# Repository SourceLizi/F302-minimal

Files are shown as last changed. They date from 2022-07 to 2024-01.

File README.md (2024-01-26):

# STM32F302C8T6最小系统

这个硬件项目是用于取代原先F103C8T6开发板而制作的，也为其他硬件项目提供参考。相比于同等密度的F103，STM32F302拥有一个高速（5MSPS）ADC，并且额外增加了一个运放和三个比较器，适合模数混合的应用。另外由于其定时器带有输入时钟倍频的功能，其输出分辨率比F103更高。

板载功能除了必须的调试口，复位电路以及晶振电路之外，还引出了USB接口与两枚测试用的LED，另外还增加了一颗IMU（QMI8658C）的位置，用于实践测试IMU解算算法以及评估IMU性能。

最小系统板还配备了一块带有三个半桥驱动的底板（原来的目的是用于驱动电机，后面发现不符合要求），适合用于作为功率级使用。三个半桥均带有电流检测的功能。由核心板的5V经过升压达到11V输入驱动IC，而电流检测放大器的供电则由5V经线性稳压供电。
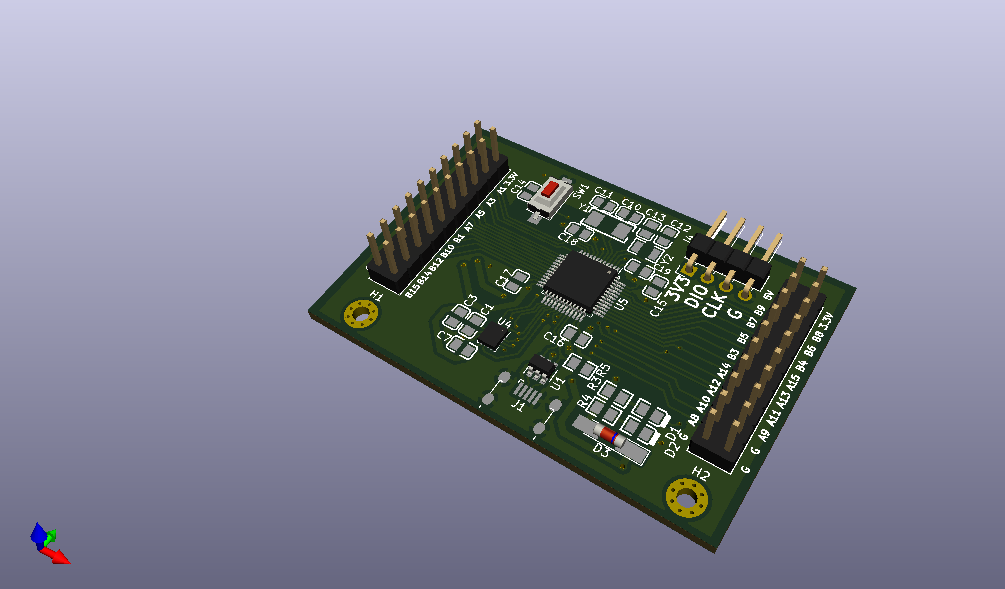
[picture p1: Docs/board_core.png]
board_core


## 硬件说明

1. 最小系统板内主控的模拟电源与数字电源可分开供电，可以选择使用额外的LDO LP5907为模拟电源供电，或者拖锡连接JP1直接连接模数电源

2. AMS1117输入输出的二极管D3必须焊接，否则会出现在调试时只接入3.3V而1117发热严重的情况

3. IMU的中断管脚INT1与栅极驱动底板的驱动输入引脚有冲突，按照目前的设计二选其一使用

## 软件说明

`f302_minimal_test` 内为早期测试核心板的代码，基本没有实际用途

`imu_f302` 内为IMU测试解算代码，读取QMI8658C解算角度，并将其通过USB虚拟串口发送至匿名地面站上位机。EKF解算算法详见[这篇博客](https://sourcelizi.github.io/202304/imu-practice/)，新增加的ESKF解算算法见[这篇博客](https://sourcelizi.github.io/202311/imu-practice3/)

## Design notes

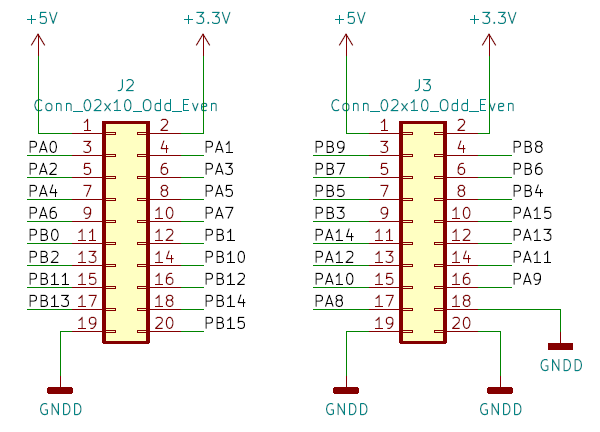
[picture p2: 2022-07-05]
Hardware/Core/pinout.png

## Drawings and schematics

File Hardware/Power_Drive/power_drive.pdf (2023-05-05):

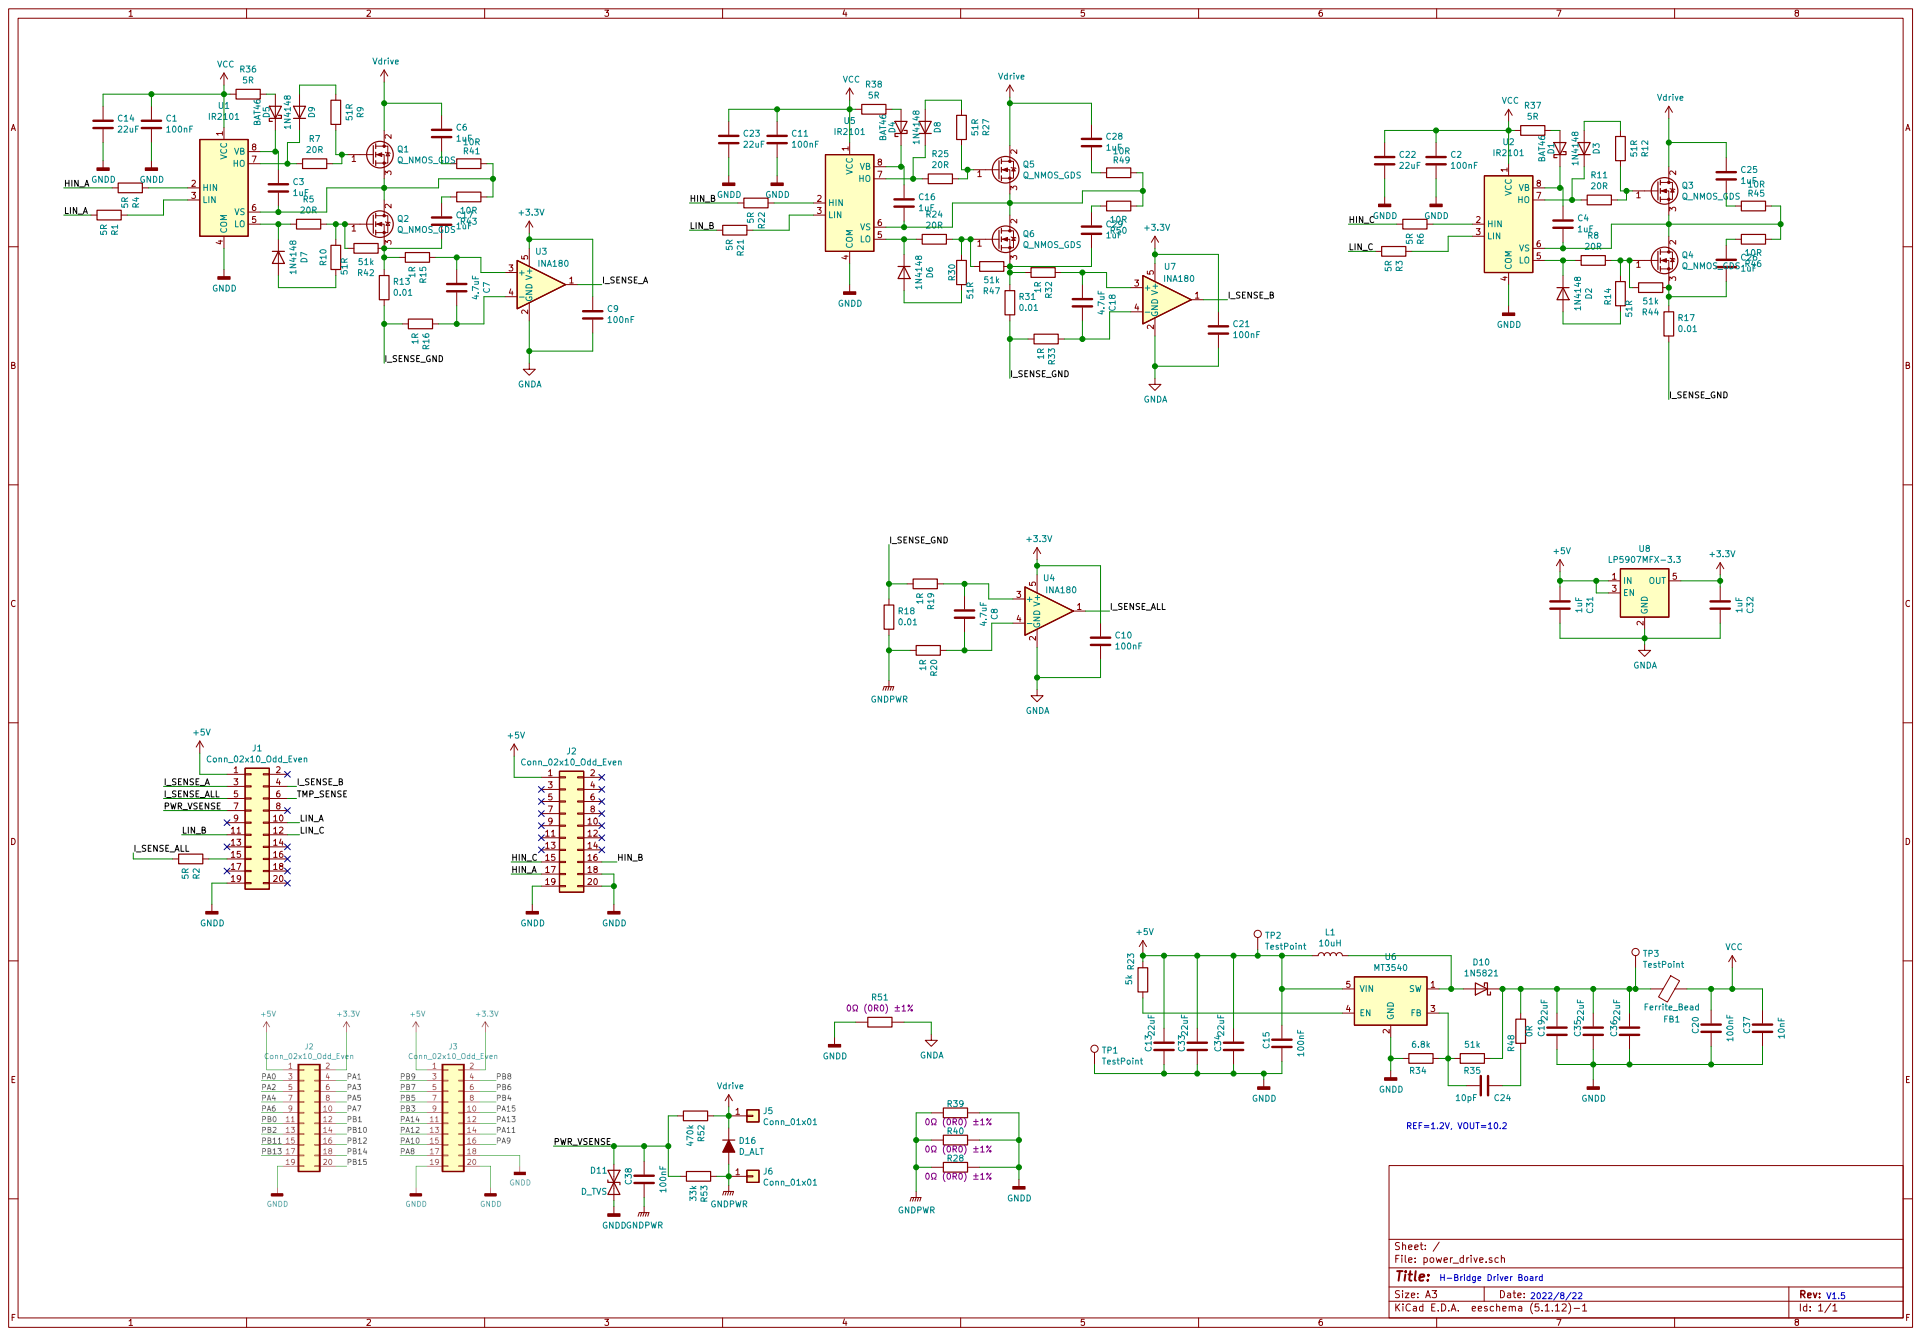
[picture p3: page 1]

H-Bridge Driver Board REF=1.2V, VOUT=10.2

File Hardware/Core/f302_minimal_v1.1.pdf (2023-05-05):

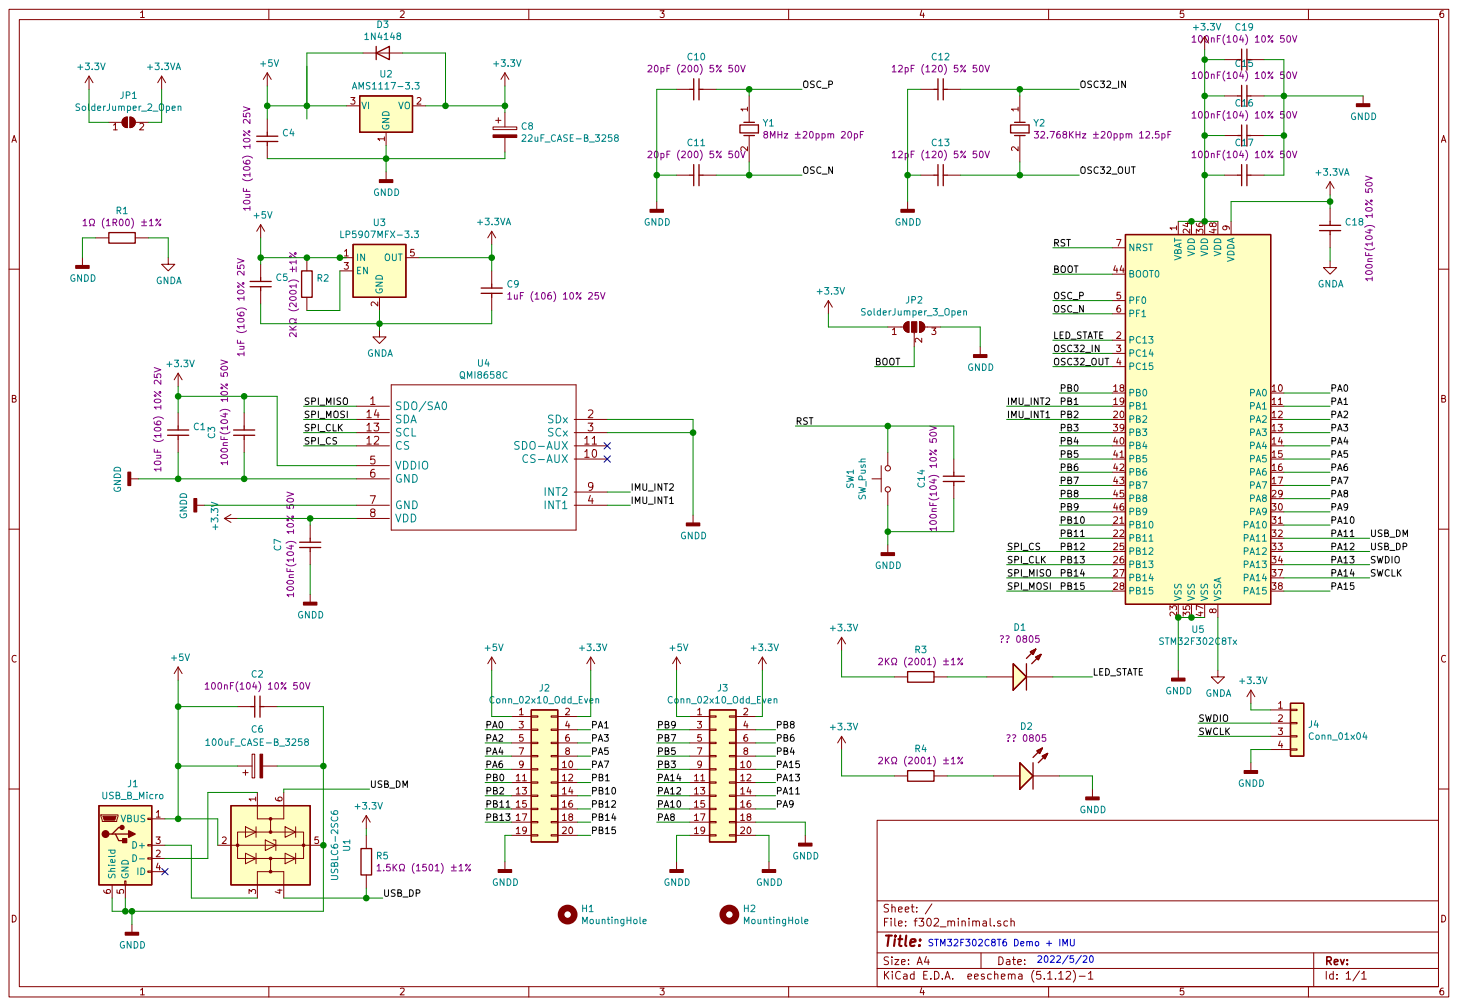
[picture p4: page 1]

1 VDD 24 VDD 36 VDD 48 VDDA

9 VSS 23 VSS 35 VSS 47 VSSA

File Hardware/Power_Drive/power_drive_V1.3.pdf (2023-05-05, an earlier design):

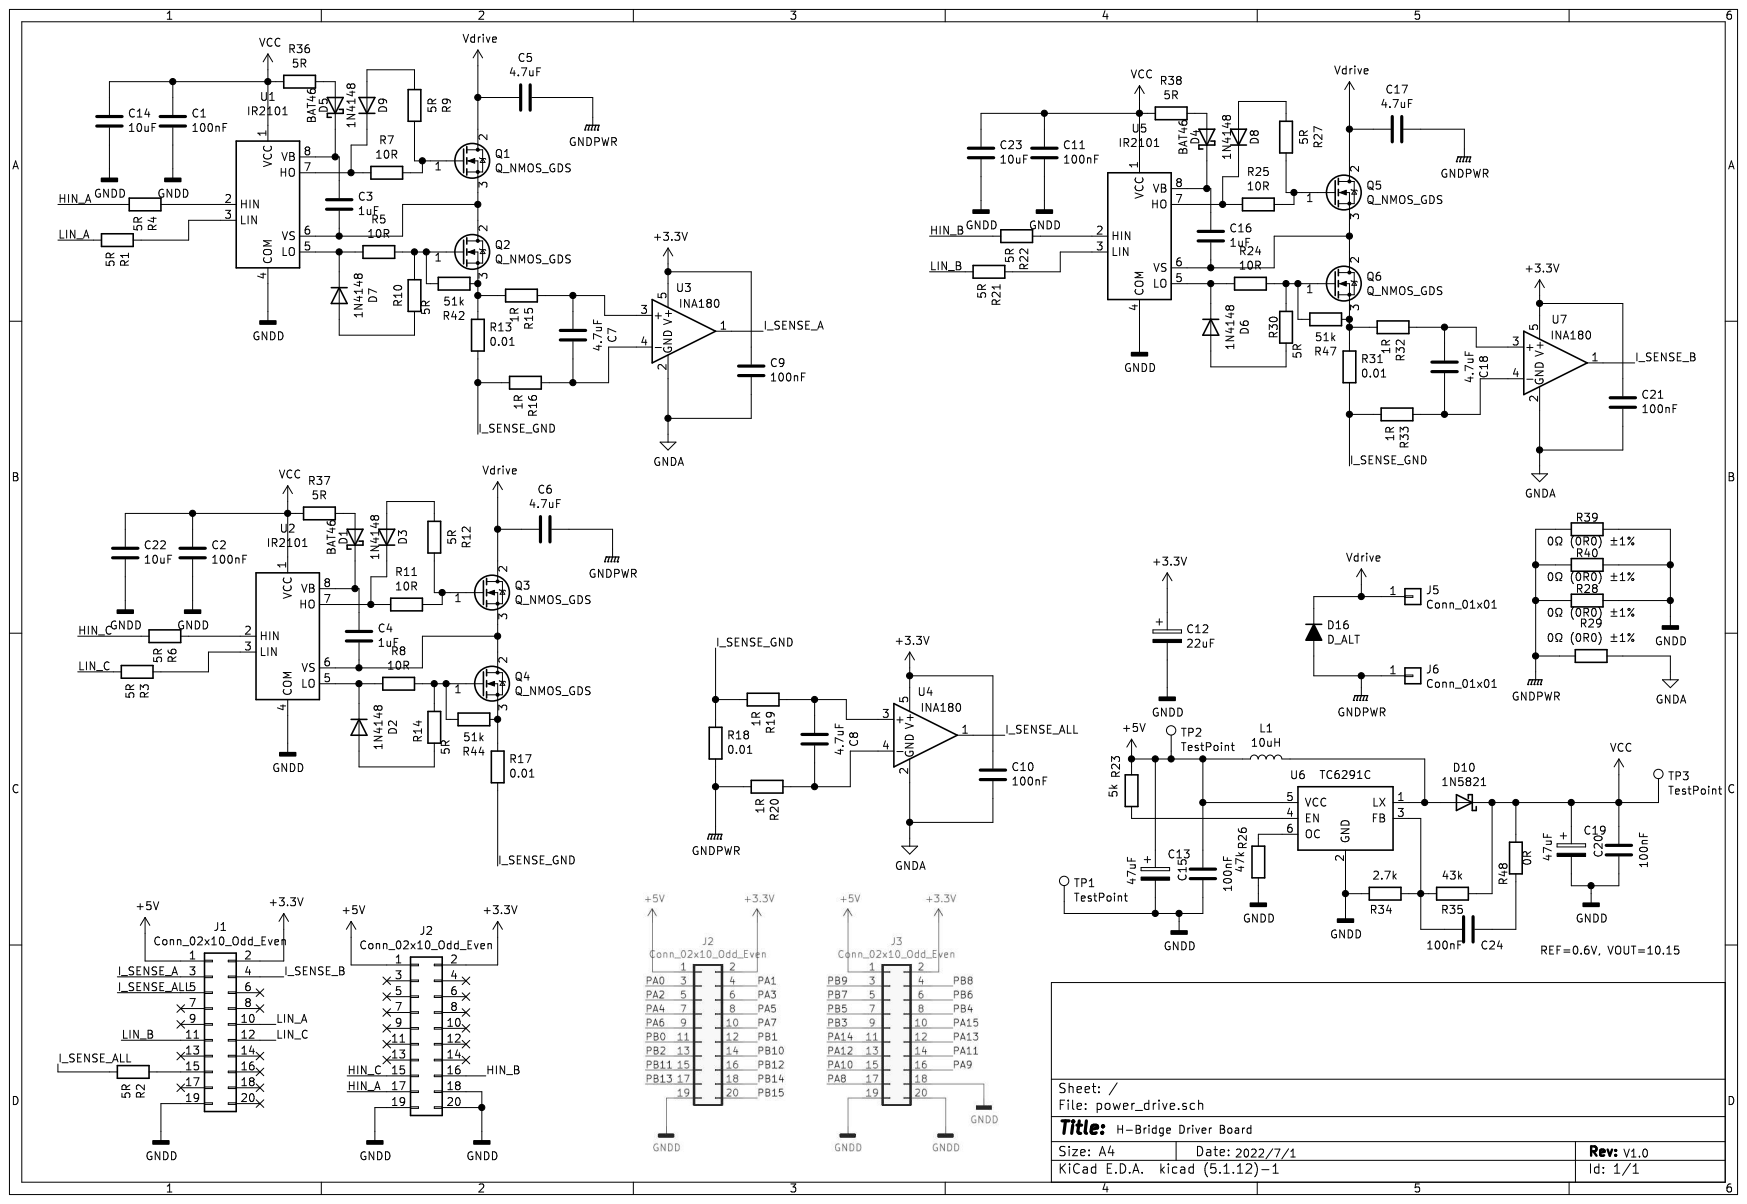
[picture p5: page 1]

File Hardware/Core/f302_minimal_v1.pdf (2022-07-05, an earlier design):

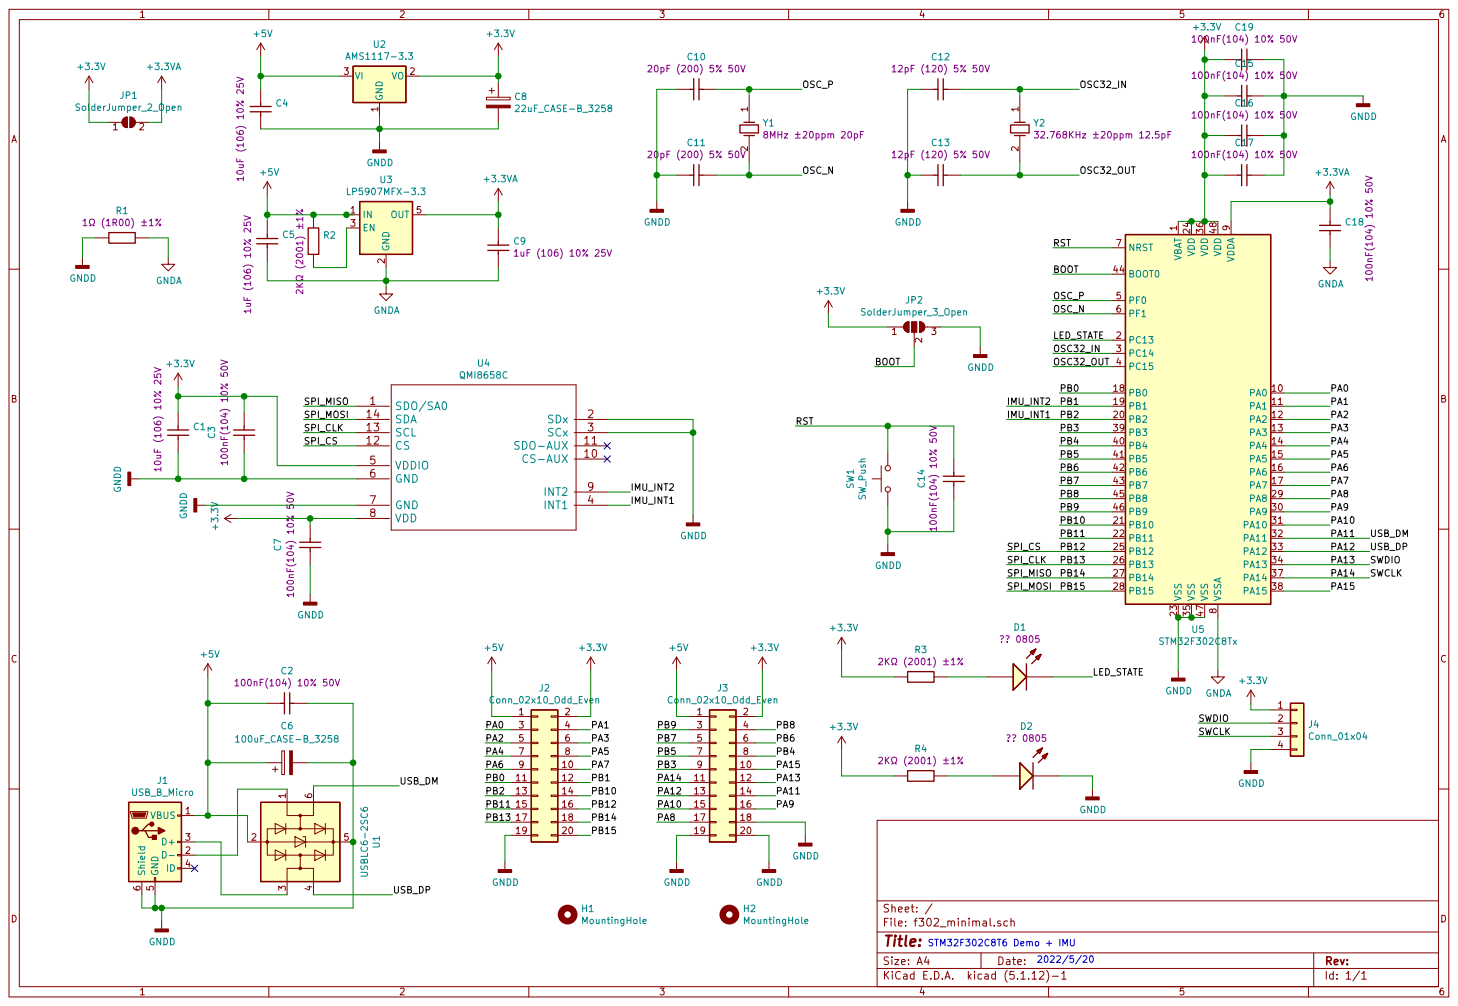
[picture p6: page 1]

1 VO 2 VI 3 U2 AMS1117-3.3 BOOT0 44 NRST 7 PA0 10 PA1 11 PA10 31 PA11 32 PA12 33 PA13 34 PA14 37 PA15 38 PA2 12 PA3 13 PA4 14 PA5 15 PA6 16 PA7 17 PA8 29 PA9 30 PB0 18 PB1 19 PB10 21 PB11 22 PB12 25 PB13 26 PB14 27 PB15 28 PB2 20 PB3 39 PB4 40 PB5 41 PB6 42 PB7 43 PB8 45 PB9 46 PC13 2 PC14 3 PC15 4 PF0 5 PF1 6 VBAT

1 VDD 24 VDD 36 VDD 48 VDDA

9 VSS 23 VSS 35 VSS 47 VSSA

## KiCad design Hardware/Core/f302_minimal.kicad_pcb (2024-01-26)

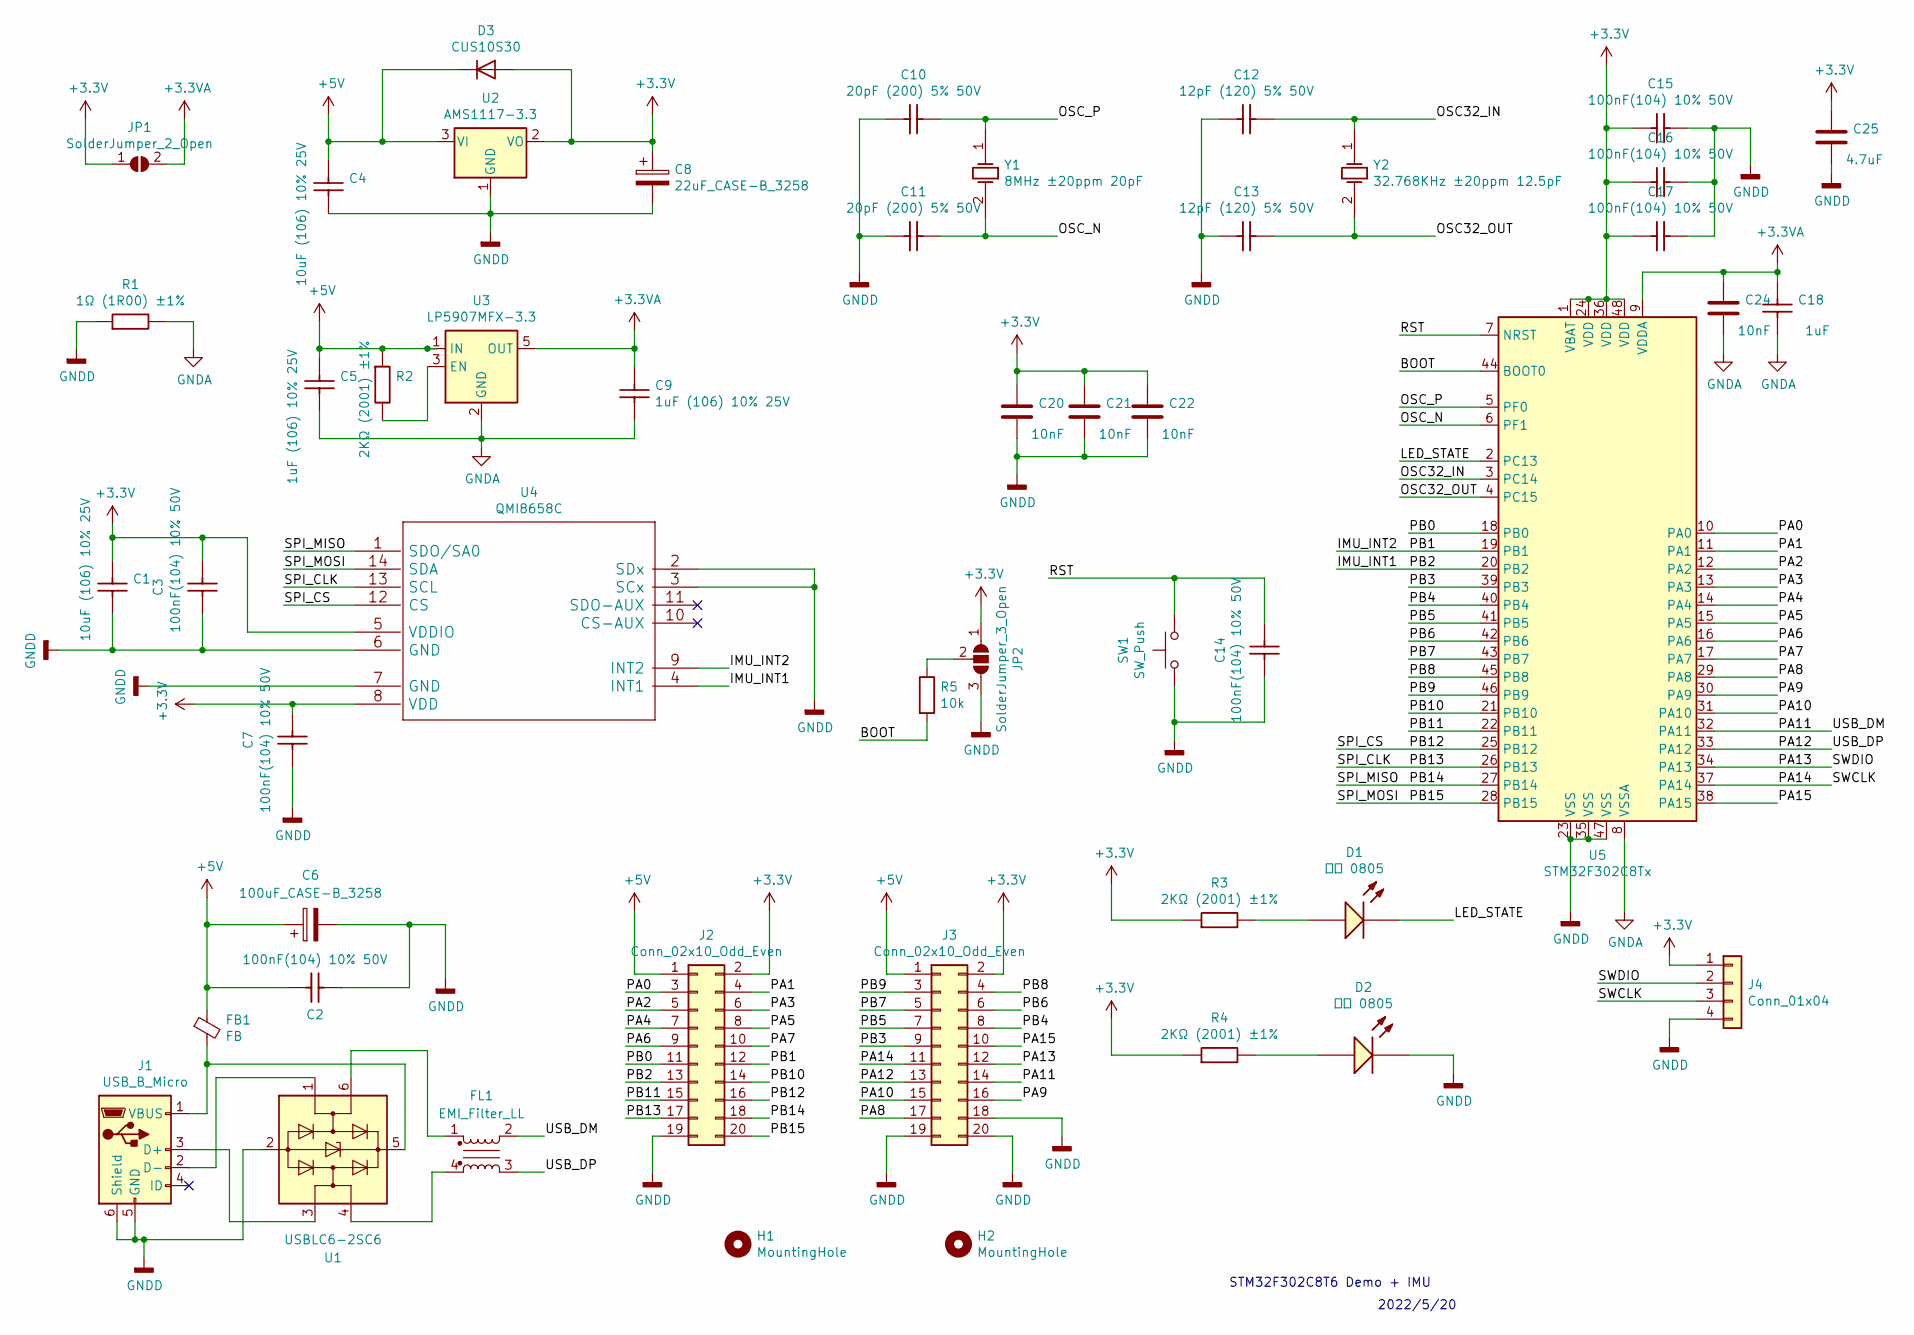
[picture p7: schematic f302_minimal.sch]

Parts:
C1, C4, C5, C9: 0805_10uF__106_10%_25V; 0805_C
C2, C3, C7, C14, C15, C16, C17: 0805_100nF_104_10%_50V; 0805_C
C6: 100uF_CASE-B_3258; CP_EIA-3528-21_Kemet-B_Pad1.50x2.35mm_HandSolder
C8: 22uF_CASE-B_3258; CP_EIA-3528-21_Kemet-B_Pad1.50x2.35mm_HandSolder
C10, C11: 0805_20pF__200_5%_50V; 0805_C
C12, C13: 0805_12pF__120_5%_50V; 0603_C
C18: 1uF; 0805_C
C20, C21, C22, C24: 10nF; C_0603_1608Metric_Pad1.08x0.95mm_HandSolder
C25: 4.7uF; C_0805_2012Metric_Pad1.18x1.45mm_HandSolder
D1: 0805_翠绿; 0805_LED_S1
D2: 0805_红灯; 0805_LED_S1
D3: CUS10S30; D_SOD-323_HandSoldering
FB1: FB; R_0805_2012Metric_Pad1.20x1.40mm_HandSolder
FL1: EMI_Filter_LL; DLW21SN900SQ2L
H1, H2: MountingHole; MountingHole_2.2mm_M2_Pad_Via
J1: USB_B_Micro; USB_MicroB
J2, J3: Conn_02x10_Odd_Even; PinHeader_2x10_P2.54mm_Vertical
J4: Conn_01x04; PinHeader_1x04_P2.54mm_Horizontal
JP1: SolderJumper_2_Open; SolderJumper-2_P1.3mm_Open_RoundedPad1.0x1.5mm
JP2: SolderJumper_3_Open; SolderJumper-3_P1.3mm_Open_RoundedPad1.0x1.5mm_NumberLabels
R1: 0603_1Ω__1R00_1%; 0603_R
R2, R3, R4: 0805_2KΩ__2001_1%; 0805_R
R5: 10k; R_0603_1608Metric_Pad0.98x0.95mm_HandSolder
SW1: SW_Push; SW_SPST_CK_RS282G05A3
U1: USBLC6-2SC6; SOT-23-6_Handsoldering
U2: AMS1117-3.3; SOT-223-3_TabPin2
U3: LP5907MFX-3.3; SOT-23-5
U4: QMI8658C; Bosch_LGA-14_3x2.5mm_P0.5mm
U5: STM32F302C8Tx; LQFP-48_7x7mm_P0.5mm
Y1: SMD-5032_2P_8MHz_20ppm_20pF; SMD-5032_2P
Y2: SMD-3215_2P_32.768KHz_20ppm_12.5pF; SMD-3215_2P_FC_-_135

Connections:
+3.3VA: C9.2, C18.1, C24.1, JP1.2 (B), U3.5 (OUT), U5.9 (VDDA)
+3V3: C1.1, C3.2, C7.2, C8.1, C15.1, C16.1, C17.1, C20.1, C21.1, C22.1, C25.1, D3.2 (A), J2.2, J3.2, J4.1, JP1.1 (A), JP2.1 (A), R3.1, R4.1, U2.2 (VO), U4.5 (VDDIO), U4.8 (VDD), U5.1 (VBAT), U5.24 (VDD), U5.36 (VDD), U5.48 (VDD)
+5V: C2.1, C4.1, C5.2, C6.1, D3.1 (K), FB1.1, J2.1, J3.1, R2.1, U2.3 (VI), U3.1 (IN)
/BOOT: R5.2, U5.44 (BOOT0)
/IMU_INT1: J2.13, U4.4 (INT1), U5.20 (PB2)
/IMU_INT2: J2.12, U4.9 (INT2), U5.19 (PB1)
/LED_STATE: D1.K, U5.2 (PC13)
/OSC32_IN: C12.2, U5.3 (PC14), Y2.1 (OSC1)
/OSC32_OUT: C13.2, U5.4 (PC15), Y2.2 (OSC2)
/OSC_N: C11.2, U5.6 (PF1), Y1.2 (OSC2)
/OSC_P: C10.2, U5.5 (PF0), Y1.1 (OSC1)
/PA0: J2.3, U5.10 (PA0)
/PA1: J2.4, U5.11 (PA1)
/PA2: J2.5, U5.12 (PA2)
/PA3: J2.6, U5.13 (PA3)
/PA4: J2.7, U5.14 (PA4)
/PA5: J2.8, U5.15 (PA5)
/PA6: J2.9, U5.16 (PA6)
/PA7: J2.10, U5.17 (PA7)
/PA8: J3.17, U5.29 (PA8)
/PA9: J3.16, U5.30 (PA9)
/PA10: J3.15, U5.31 (PA10)
/PA11: FL1.2, J3.14, U5.32 (PA11)
/PA12: FL1.3, J3.13, U5.33 (PA12)
/PA13: J3.12, J4.2, U5.34 (PA13)
/PA14: J3.11, J4.3, U5.37 (PA14)
/PA15: J3.10, U5.38 (PA15)
/PB0: J2.11, U5.18 (PB0)
/PB3: J3.9, U5.39 (PB3)
/PB4: J3.8, U5.40 (PB4)
/PB5: J3.7, U5.41 (PB5)
/PB6: J3.6, U5.42 (PB6)
/PB7: J3.5, U5.43 (PB7)
/PB8: J3.4, U5.45 (PB8)
/PB9: J3.3, U5.46 (PB9)
/PB10: J2.14, U5.21 (PB10)
/PB11: J2.15, U5.22 (PB11)
/PB12: J2.16, U4.12 (CS), U5.25 (PB12)
/PB13: J2.17, U4.13 (SCL), U5.26 (PB13)
/PB14: J2.18, U4.1 (SDO/SA0), U5.27 (PB14)
/PB15: J2.20, U4.14 (SDA), U5.28 (PB15)
/RST: C14.2, SW1.2, U5.7 (NRST)
GNDA: C5.1, C9.1, C18.2, C24.2, R1.2, U3.2 (GND), U5.8 (VSSA)
GNDD: C1.2, C2.2, C3.1, C4.2, C6.2, C7.1, C8.2, C10.1, C11.1, C12.1, C13.1, C14.1, C15.2, C16.2, C17.2, C20.2, C21.2, C22.2, C25.2, D2.K, J1.5 (GND), J1.6 (Shield), J2.19, J3.18, J3.19, J3.20, J4.4, JP2.3 (B), R1.1, SW1.1, U1.2 (GND), U2.1 (GND), U4.2 (SDx), U4.3 (SCx), U4.6 (GND), U4.7 (GND), U5.23 (VSS), U5.35 (VSS), U5.47 (VSS); also elsewhere on the board
unnamed: D1.A, R3.2
unnamed: D2.A, R4.2
unnamed 46: FB1.2, J1.1 (VBUS), U1.5 (VBUS); also elsewhere on the board
unnamed: FL1.1, U1.6 (I/O1)
unnamed: FL1.4, U1.4 (I/O2)
unnamed 49: J1.2 (D-), U1.1 (I/O1); also elsewhere on the board
unnamed 50: J1.3 (D+), U1.3 (I/O2); also elsewhere on the board
unnamed 51: J1.4 (ID); also elsewhere on the board
unnamed: JP2.2 (C), R5.1
unnamed: R2.2, U3.3 (EN)

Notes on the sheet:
STM32F302C8T6 Demo + IMU
2022/5/20

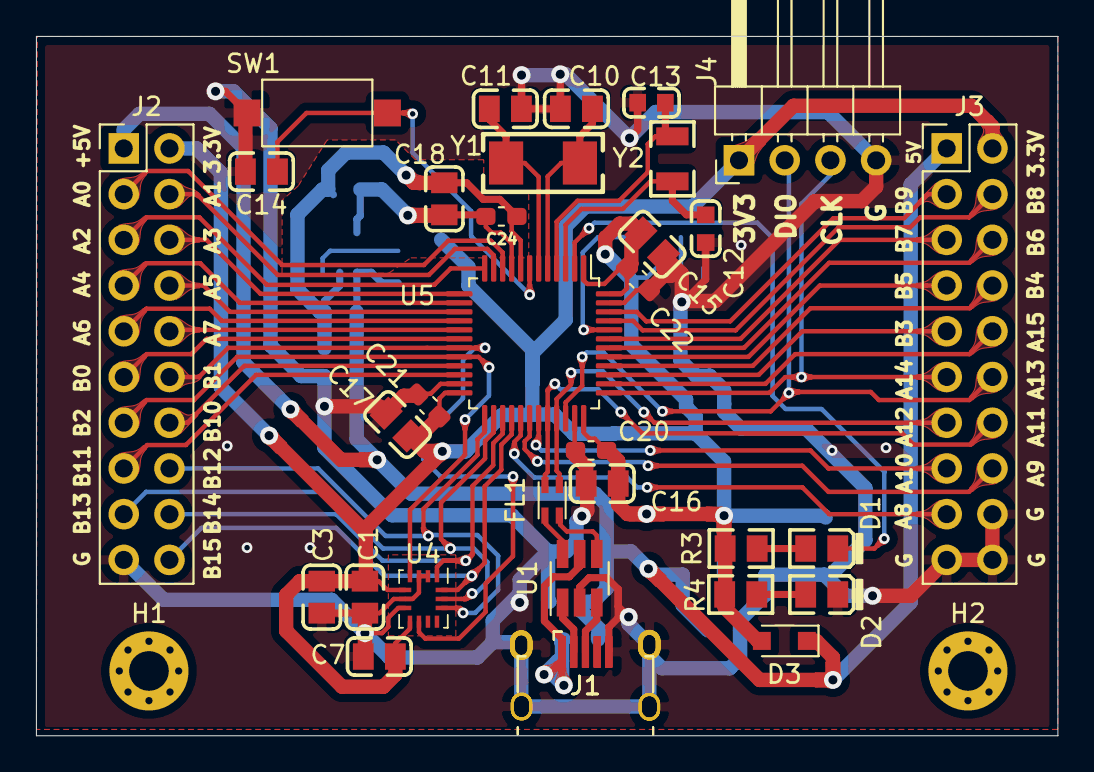
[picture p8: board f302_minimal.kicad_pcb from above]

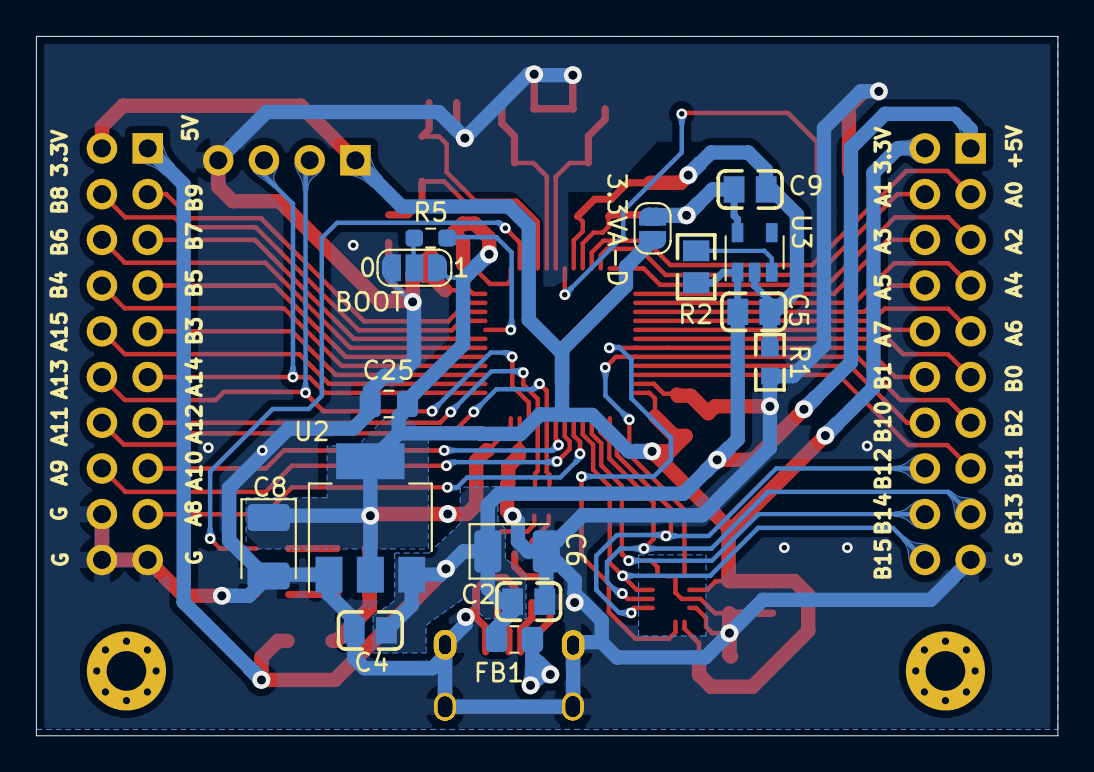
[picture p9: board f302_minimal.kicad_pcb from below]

Board: 2 copper layers, 56.8 x 38.8 mm, 50 parts (15 on the bottom side), 54 nets.

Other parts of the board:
J1#2: USB_B_Micro; USB_MicroB

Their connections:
GNDD: J1#2.5, J1#2.6; also elsewhere on the board
unnamed 46: J1#2.1; also elsewhere on the board
unnamed 49: J1#2.2; also elsewhere on the board
unnamed 50: J1#2.3; also elsewhere on the board
unnamed 51: J1#2.4; also elsewhere on the board

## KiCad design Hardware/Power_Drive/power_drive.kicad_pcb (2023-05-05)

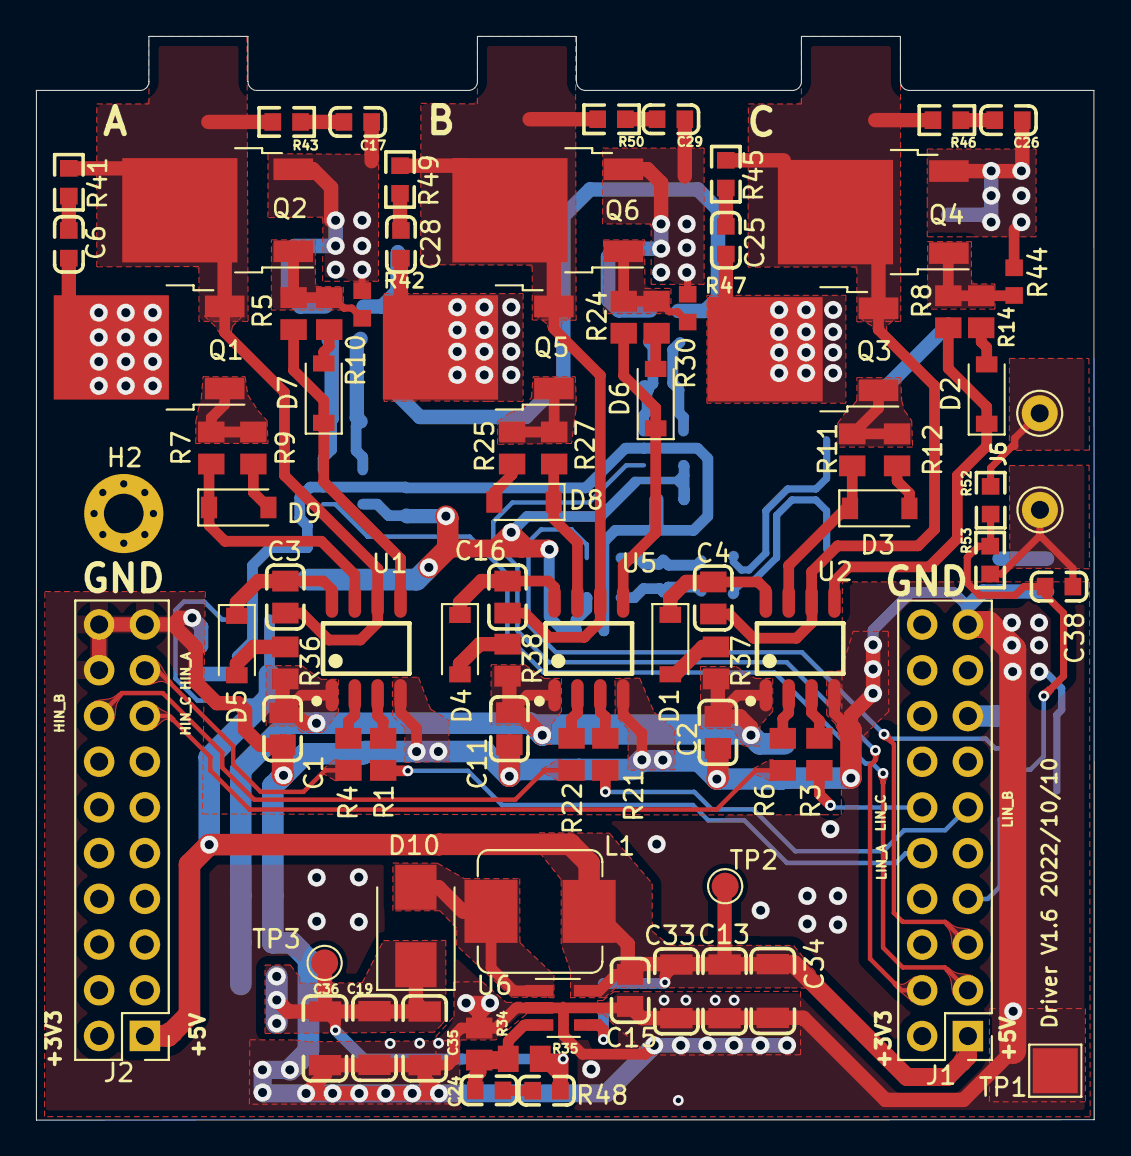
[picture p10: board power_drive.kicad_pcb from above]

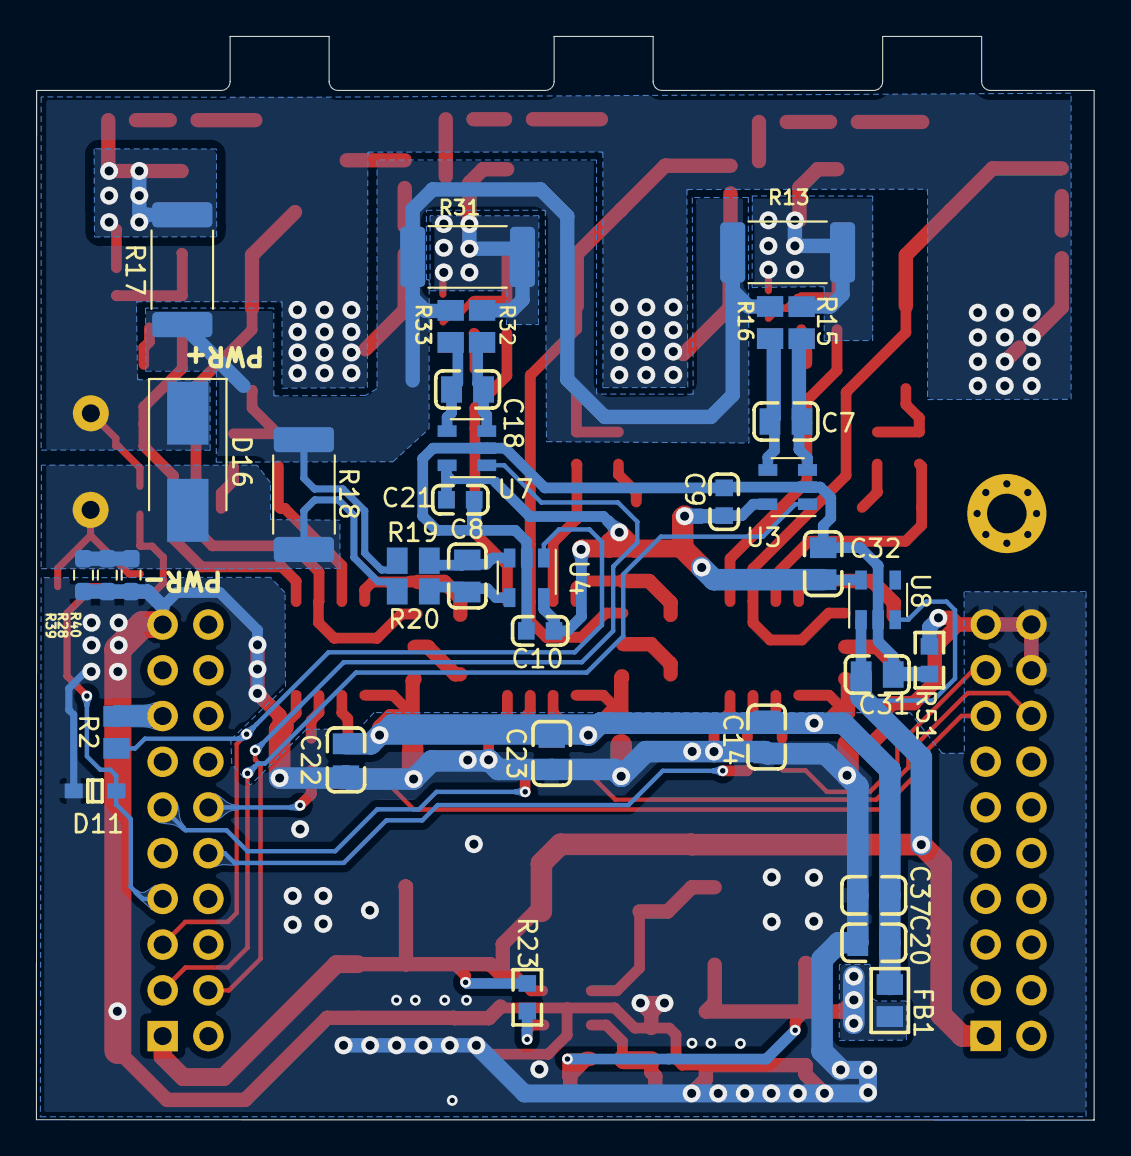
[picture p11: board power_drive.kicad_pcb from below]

Board: 2 copper layers, 58.8 x 60.2 mm, 121 parts (36 on the bottom side), 72 nets.

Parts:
C1, C2, C11, C15, C20: 100nF; 0805_C
C3, C4, C16, C31, C32: 1uF; 0805_C
C6, C17, C25, C26, C28, C29: 1uF; 0603_C
C7, C8, C18: 4.7uF; 0805_C
C9, C10, C21, C38: 100nF; 0603_C
C13, C19, C33, C34, C35, C36: 22uF; 1206_C
C14, C22, C23: 22uF; 0805_C
C24: 10pF; 0603_C
C37: 10nF; 0805_C
D1, D4, D5: BAT46; D_SOD-123
D2, D3, D6, D7, D8, D9: 1N4148; D_SOD-123
D10: 1N5821; D_SMB
D11: D_TVS; SOD-323
D16: D_ALT; D_SMB_Handsoldering
FB1: Ferrite_Bead; 0805_L
H2: MountingHole; MountingHole_2.2mm_M2_Pad_Via
J1, J2: Conn_02x10_Odd_Even; PinHeader_2x10_P2.54mm_Vertical
J5, J6: Conn_01x01; Pin_D1.0mm_L10.0mm
L1: 10uH; L_Bourns_SRP7028A_7.3x6.6mm
Q1, Q2, Q3, Q4, Q5, Q6: Q_NMOS_GDS; TO-252-2
R1, R2, R3, R4, R6, R21, R22, R36, R37, R38: 5R; 0805
R5, R7, R8, R11, R24, R25: 20R; 0805
R9, R10, R12, R14, R27, R30: 51R; 0805
R13, R17, R18, R31: 0.01; R_2512_6332Metric_Pad1.40x3.35mm_HandSolder
R15, R16, R19, R20, R32, R33: 1R; 0805
R23: 5k; 0603_R
R28, R39, R40: 0603_0Ω__0R0_1%; R_0603_1608Metric_Pad0.98x0.95mm_HandSolder
R34: 6.8k; 0805
R35: 51k; 0805
R41, R43, R45, R46, R49, R50: 10R; 0603_R
R42, R44, R47: 51k; 0603
R48: 0R; 0603_C
R51: 0603_0Ω__0R0_1%; 0603_R
R52: 470k; 0603_R
R53: 33k; 0603_R
TP1: TestPoint; TestPoint_Pad_2.5x2.5mm
TP2, TP3: TestPoint; TestPoint_Pad_D1.5mm
U1, U2, U5: IR2101; SOP-8_150MIL
U3, U4, U7: INA180; SOT-23-5
U6: MT3540; SOT-23-5_HandSoldering
U8: LP5907MFX-3.3; SOT-23-5

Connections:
+3V3: C9.2, C10.2, C21.2, C32.2, U3.5, U4.5, U7.5, U8.5
+5V: C13.2, C15.2, C31.2, C33.2, C34.2, J1.1, J2.1, L1.1, R23.1, TP2.1, U6.5, U8.1, U8.3
/HIN_A: J2.17, R4.1
/HIN_B: J2.16, R22.1
/HIN_C: J2.15, R6.1
/I_SENSE_A: J1.3, U3.1
/I_SENSE_ALL: J1.5, R2.1, U4.1
/I_SENSE_B: J1.4, U7.1
/I_SENSE_GND: R13.1, R16.1, R17.1, R18.2, R19.1, R31.1, R33.1
/LIN_A: J1.10, R1.1
/LIN_B: J1.11, R21.1
/LIN_C: J1.12, R3.1
/PWR_VSENSE: C38.2, D11.1, J1.7, R52.1, R53.1
GNDA: C9.1, C10.1, C21.1, C31.1, C32.1, R51.2, U3.2, U4.2, U7.2, U8.2
GNDD: C1.1, C2.1, C11.1, C13.1, C14.1, C15.1, C19.1, C20.1, C22.1, C23.1, C33.1, C34.1, C35.1, C36.1, C37.1, D11.2, J1.19, J2.18, J2.19, J2.20, R28.2, R34.2, R39.2, R40.2, R51.1, TP1.1, U1.4, U2.4, U5.4, U6.2
GNDPWR: C38.1, D16.2, J6.1, R18.1, R20.1, R28.1, R39.1, R40.1, R53.2
unnamed: C3.1, Q1.3, Q2.2, R41.2, R43.2, U1.6
unnamed: C3.2, D5.1, U1.8
unnamed: C4.1, Q3.3, Q4.2, R45.2, R46.2, U2.6
unnamed: C4.2, D1.1, U2.8
unnamed: C6.1, R41.1
unnamed: C7.1, R16.2, U3.4
unnamed: C7.2, R15.2, U3.3
unnamed: C8.1, R20.2, U4.4
unnamed: C8.2, R19.2, U4.3
unnamed: C16.1, Q5.3, Q6.2, R49.2, R50.2, U5.6
unnamed: C16.2, D4.1, U5.8
unnamed: C17.1, Q2.3, R13.2, R15.1, R42.2
unnamed: C17.2, R43.1
unnamed: C18.1, R33.2, U7.4
unnamed: C18.2, R32.2, U7.3
unnamed: C19.2, C35.2, C36.2, D10.1, FB1.2, R35.1, R48.2, TP3.1
unnamed: C24.1, R48.1
unnamed: C24.2, R34.1, R35.2, U6.3
unnamed: C25.1, R45.1
unnamed: C26.1, Q4.3, R17.2, R44.2
unnamed: C26.2, R46.1
unnamed: C28.1, R49.1
unnamed: C29.1, Q6.3, R31.2, R32.1, R47.2
unnamed: C29.2, R50.1
unnamed: D1.2, R37.1
unnamed: D2.1, R8.2, U2.5
unnamed: D2.2, R14.1
unnamed: D3.1, R11.2, U2.7
unnamed: D3.2, R12.2
unnamed: D4.2, R38.1
unnamed: D5.2, R36.1
unnamed: D6.1, R24.2, U5.5
unnamed: D6.2, R30.1
unnamed: D7.1, R5.2, U1.5
unnamed: D7.2, R10.1
unnamed: D8.1, R25.2, U5.7
unnamed: D8.2, R27.2
unnamed: D9.1, R7.2, U1.7
unnamed: D9.2, R9.2
unnamed: D10.2, L1.2, U6.1
unnamed: J1.15, R2.2
unnamed: Q1.1, R7.1, R9.1
unnamed: Q2.1, R5.1, R10.2, R42.1
unnamed: Q3.1, R11.1, R12.1
unnamed: Q4.1, R8.1, R14.2, R44.1
unnamed: Q5.1, R25.1, R27.1
unnamed: Q6.1, R24.1, R30.2, R47.1
unnamed: R1.2, U1.3
unnamed: R3.2, U2.3
unnamed: R4.2, U1.2
unnamed: R6.2, U2.2
unnamed: R21.2, U5.3
unnamed: R22.2, U5.2
unnamed: R23.2, U6.4
VCC: C1.2, C2.2, C11.2, C14.2, C20.2, C22.2, C23.2, C37.2, FB1.1, R36.2, R37.2, R38.2, U1.1, U2.1, U5.1
Vdrive: C6.2, C25.2, C28.2, D16.1, J5.1, Q1.2, Q3.2, Q5.2, R52.2

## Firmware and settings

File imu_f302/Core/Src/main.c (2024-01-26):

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
/* Includes ------------------------------------------------------------------*/
#include "main.h"
#include "usb_device.h"

/* USER CODE BEGIN Includes */
#include "imu_eskf.h"
#include "usbd_cdc_if.h"
/* USER CODE END Includes */

 SPI_HandleTypeDef hspi2;

TIM_HandleTypeDef htim16;
TIM_HandleTypeDef htim17;

/* USER CODE BEGIN PV */
//static uint8_t rx, tx, addr = 0x01;
uint8_t upload_flag = 0;
uint8_t first_data = 0;
//uint16_t tx_16,rx_16;
extern USBD_HandleTypeDef hUsbDeviceFS;

#define IMU_PI 3.14159265358979f

typedef struct {
	int16_t acc[3];
	int16_t gyro[3];
}gyro_acc_data_t;

typedef __packed struct{
	uint16_t header;
	uint8_t func;
	uint8_t len;
	
	int16_t ROL;
	int16_t PIT;
	int16_t YAW;
	uint16_t dummy1;
	uint32_t dummy2;
	
	uint8_t sum;
}packet_t;

uint32_t timetamp,last_timetamp = 0;
uint32_t delta_t;

uint8_t spi_byte;


packet_t upload_packet;
gyro_acc_data_t imu_data;
imu_data_f32_t imu_data_f32;
euler_t eular;
/* USER CODE END PV */

void SystemClock_Config(void);
static void MX_GPIO_Init(void);
static void MX_SPI2_Init(void);
static void MX_TIM16_Init(void);
static void MX_TIM17_Init(void);
/* USER CODE BEGIN 0 */
//void spi_read_bytes(uint8_t addr, uint8_t* rx_data,uint16_t size){
//		while((SPI2->SR & SPI_SR_BSY)==SPI_SR_BSY); 
//		HAL_GPIO_WritePin(GPIOB,GPIO_PIN_12,GPIO_PIN_RESET);//CS low
//	 
//		SPI2->DR = addr | 0x80;
//		for(int i=0;i < size; i++){
//			while((SPI2->SR & SPI_SR_BSY)==SPI_SR_BSY);
//			rx_data[i] =  SPI2->DR;
//		}
//		
//		while(HAL_GPIO_ReadPin(GPIOB,GPIO_PIN_13) == GPIO_PIN_SET);
//		//HAL_SPI_TransmitReceive(&hspi2,&tx,&rx,1,100);

//		HAL_GPIO_WritePin(GPIOB,GPIO_PIN_12,GPIO_PIN_SET);//CS high
//}

//void spi_write_bytes(uint8_t addr, uint8_t* tx_data,uint16_t size){
//	while((SPI2->SR & SPI_SR_BSY)==SPI_SR_BSY);
//	
//	HAL_GPIO_WritePin(GPIOB,GPIO_PIN_12,GPIO_PIN_RESET);//CS low  
//		SPI2->DR = addr & 0x7F;
//		for(int i=0;i < size; i++){
//			while((SPI2->SR & SPI_SR_BSY)==SPI_SR_BSY);
//			SPI2->DR = tx_data[i];
//		}
//		while((SPI2->SR & SPI_SR_BSY)==SPI_SR_BSY);  
//		while(HAL_GPIO_ReadPin(GPIOB,GPIO_PIN_13) == GPIO_PIN_SET);
//		//HAL_SPI_TransmitReceive(&hspi2,&tx,&rx,1,100);

//		HAL_GPIO_WritePin(GPIOB,GPIO_PIN_12,GPIO_PIN_SET);//CS high
//}

void spi_write_reg(uint8_t addr, uint8_t tx_byte){
	uint16_t rx_data, tx_data;
	tx_data  = ((uint16_t)(addr & 0x7F) << 8) | (uint16_t)tx_byte;
	HAL_SPI_TransmitReceive(&hspi2,(uint8_t*)&tx_data,(uint8_t*)&rx_data,1,100);
}

uint8_t spi_read_reg(uint8_t addr){
	uint16_t rx_data, tx_data = 0;
	tx_data  = (uint16_t)(addr | 0x80) << 8;
	HAL_SPI_TransmitReceive(&hspi2,(uint8_t*)&tx_data,(uint8_t*)&rx_data,1,100);
	return (uint8_t)(rx_data & 0xFF);
}


void HAL_TIM_PeriodElapsedCallback(TIM_HandleTypeDef *htim){
	upload_flag = 1;
}

uint8_t data_to_send[16];
#define BYTE0(dwTemp)       ( *( (char *)(&dwTemp)		) )
#define BYTE1(dwTemp)       ( *( (char *)(&dwTemp) + 1) )
#define BYTE2(dwTemp)       ( *( (char *)(&dwTemp) + 2) )
#define BYTE3(dwTemp)       ( *( (char *)(&dwTemp) + 3) )

void ANO_DT_Send_Status(float angle_rol, float angle_pit, float angle_yaw, int32_t alt, uint8_t fly_model, uint8_t armed)
{
	uint8_t _cnt=0;
	int16_t _temp;
	int32_t _temp2 = alt;
	
	data_to_send[_cnt++]=0xAA;
	data_to_send[_cnt++]=0xAA;
	data_to_send[_cnt++]=0x01;
	data_to_send[_cnt++]=0;
	
	_temp = (int)(angle_rol*100);
	data_to_send[_cnt++]=BYTE1(_temp);
	data_to_send[_cnt++]=BYTE0(_temp);
	_temp = (int)(angle_pit*100);
	data_to_send[_cnt++]=BYTE1(_temp);
	data_to_send[_cnt++]=BYTE0(_temp);
	_temp = (int)(angle_yaw*100);
	data_to_send[_cnt++]=BYTE1(_temp);
	data_to_send[_cnt++]=BYTE0(_temp);
	
	data_to_send[_cnt++]=BYTE3(_temp2);
	data_to_send[_cnt++]=BYTE2(_temp2);
	data_to_send[_cnt++]=BYTE1(_temp2);
	data_to_send[_cnt++]=BYTE0(_temp2);
	
	data_to_send[_cnt++] = fly_model;
	
	data_to_send[_cnt++] = armed;
	
	data_to_send[3] = _cnt-4;
	
	uint8_t sum = 0;
	for(uint8_t i=0;i<_cnt;i++)
		sum += data_to_send[i];
	data_to_send[_cnt++]=sum;
	
	CDC_Transmit_FS((uint8_t*)data_to_send, _cnt);
}

/* USER CODE END 0 */

/**
  * @brief  The application entry point.
  * @retval int
  */
int main(void)
{
  /* MCU Configuration--------------------------------------------------------*/

  /* Reset of all peripherals, Initializes the Flash interface and the Systick. */
  HAL_Init();

  /* Configure the system clock */
  SystemClock_Config();

  /* Initialize all configured peripherals */
  MX_GPIO_Init();
  MX_SPI2_Init();
  MX_USB_DEVICE_Init();
  MX_TIM16_Init();
  MX_TIM17_Init();
  /* Infinite loop */
  /* USER CODE BEGIN WHILE */
	//__HAL_SPI_ENABLE(&hspi2);
	
	HAL_Delay(2000);
//	tx = 0x01;
//	spi_write_bytes(0x60,&tx,1);
//	HAL_Delay(20);
//	
//	tx = 0x7F;
//	spi_write_bytes(0x08,&tx,1);
//	HAL_Delay(80);
	spi_write_reg(0x60, 0x01);
	HAL_Delay(30);
	spi_write_reg(0x02,0x60);
	spi_write_reg(0x08,0x03);
	spi_write_reg(0x03,0x22); //+-8g , 2khz
	spi_write_reg(0x04, 0x72); //2048dps, 2khz
	//spi_write_reg(0x06, 0x55);
	imu_eskf_init();
	upload_packet.header = 0xAAAA;
	upload_packet.func = 0x01;
	upload_packet.len = 12;
	
	HAL_Delay(20);
	
	HAL_TIM_Base_Start_IT(&htim16); //10Hz
	
	last_timetamp = 0;
	TIM17->CNT = 0;
	HAL_TIM_Base_Start(&htim17); 
	
  while (1)
  {
    /* USER CODE END WHILE */

    /* USER CODE BEGIN 3 */
		//spi_read_bytes(addr,&rx,1);
		spi_byte = spi_read_reg(0x2E); //STATUS0
		if((spi_byte & 0x03) == 0x03){
				timetamp = TIM17->CNT;
				for(int i=0;i<12;i++){
						((uint8_t*)&imu_data)[i] = spi_read_reg(0x35+i);
				}
		//		for(int i=0;i<3;i++){
		//				((uint8_t*)&timetamp)[i] = spi_read_reg(0x30+i);
		//		}
				if(timetamp < last_timetamp){
					delta_t = (65536 - last_timetamp) + timetamp;
				}else{
					delta_t = timetamp - last_timetamp;
				}
				last_timetamp = timetamp;
				
				imu_data_f32.ax = imu_data.acc[0] / 32768.0f * 8.0f;
				imu_data_f32.ay = imu_data.acc[1] / 32768.0f * 8.0f;
				imu_data_f32.az = imu_data.acc[2] / 32768.0f * 8.0f;
				
				imu_data_f32.gx = (imu_data.gyro[0]+133) / 32768.0f * 2048 /180*IMU_PI ;
				imu_data_f32.gy = (imu_data.gyro[1]+31) / 32768.0f * 2048/180*IMU_PI;
				imu_data_f32.gz = (imu_data.gyro[2]+11) / 32768.0f * 2048/180*IMU_PI;
				
				imu_eskf_update(&imu_data_f32, ((float)delta_t)/1000000.0f);
				imu_eskf_eular(&eular);
				
				if(upload_flag){
					upload_flag = 0;
					if(hUsbDeviceFS.dev_state == USBD_STATE_CONFIGURED){
						ANO_DT_Send_Status(-eular.roll, eular.pitch, -eular.yaw, 0,0,0);
						HAL_GPIO_TogglePin(GPIOC, GPIO_PIN_13);
					}else{
						HAL_GPIO_WritePin(GPIOC, GPIO_PIN_13,GPIO_PIN_SET);
					}
				}
			}
//		
//		//spi_read_bytes(0x3B,(uint8_t*)gyro_data,6);
//		
		//HAL_GPIO_TogglePin(GPIOC,GPIO_PIN_13);
		//HAL_Delay(1);
		
		
  }
  /* USER CODE END 3 */
}

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


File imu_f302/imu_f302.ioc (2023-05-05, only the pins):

Mcu.UserName=STM32F302C8Tx
PA11.Signal=USB_DM
PA12.Signal=USB_DP
PA13.Signal=SYS_JTMS-SWDIO
PA14.Signal=SYS_JTCK-SWCLK
PB12.Signal=SPI2_NSS
PB13.Signal=SPI2_SCK
PB14.Signal=SPI2_MISO
PB15.Signal=SPI2_MOSI
PC13.Signal=GPIO_Output
PF0-OSC_IN.Signal=RCC_OSC_IN
PF1-OSC_OUT.Signal=RCC_OSC_OUT

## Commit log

2022-07-05 init files
    [f302_minimal.kicad_pcb, f302_minimal.sch]
2023-05-05 hardware updated, add imu fusion code
    [f302_minimal.kicad_pcb, f302_minimal.sch, power_drive.kicad_pcb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]
2024-01-26 update hardware, add eskf code, bug fix
    [f302_minimal.kicad_pcb, f302_minimal.sch, f302_minimal_v1.1.kicad_pcb]

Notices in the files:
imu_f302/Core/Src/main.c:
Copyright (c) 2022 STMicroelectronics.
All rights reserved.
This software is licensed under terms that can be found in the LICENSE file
